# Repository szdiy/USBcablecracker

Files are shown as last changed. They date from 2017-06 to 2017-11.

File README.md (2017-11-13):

USBcablecracker
============
USB Cable Cracker is a device that measures the resistance of USB cable.
It measures the serial resistance of VCC + GND or D+ or D-.
And if you are not satisfy with the resistance, you can crack the cable by yourself.
It is a Arduino Leonardo compatible board, with some extend pins.

Schematic
------------
[PDF][schem]

BOM
------------
[CSV][bom]

PCB
------------
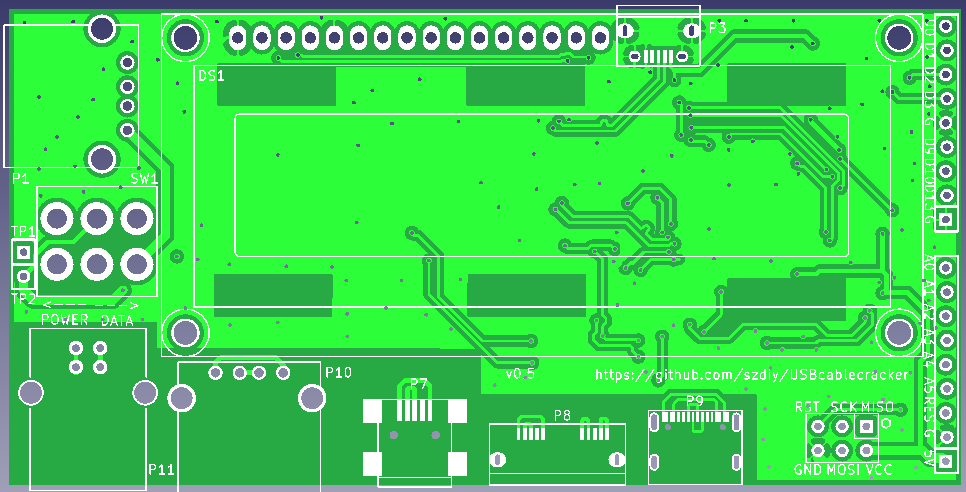
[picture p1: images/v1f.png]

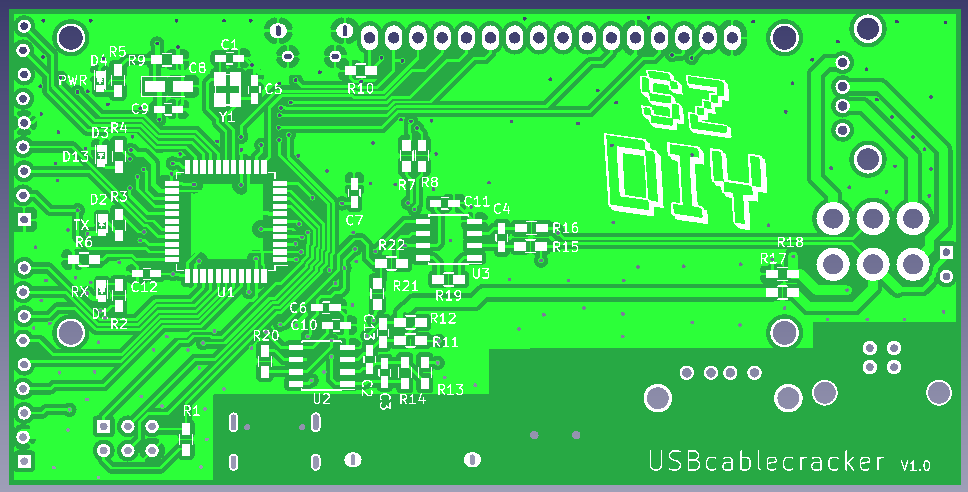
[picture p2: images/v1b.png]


Photo
------------

License
------------
This project is released under the CC BY-SA license.


Support
------------
r@szdiy.org

Where to buy
------------

[schem]:https://github.com/szdiy/USBcablecracker/raw/master/hardware/USBcablecracker.pdf
[bom]:https://github.com/szdiy/USBcablecracker/raw/master/hardware/manufature/USBcablecracker_bom.csv

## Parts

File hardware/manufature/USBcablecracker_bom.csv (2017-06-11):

Comment | Designator | Footprint
100nF/10V | C6,C9,C10,C11,C12 | C_0603
33R/1% | R18 | R_0603
68R/1% | R17 | R_0603
15PF | C1,C5 | C_0603
1nF | C2,C3,C4,C13 | C_0603
1uF | C7 | C_0603
LED_Yellow | D1 | LED_0603
TX_Green | D2 | LED_0603
LED_Blue | D3 | LED_0603
LED_Red | D4 | LED_0603
10K/1% | R1,R9,R11,R13,R15,R16,R20,R21,R22 | R_0603
1K/1% | R2,R3,R4,R5,R6 | R_0603
22R/1% | R7,R8 | R_0603
91R/1% | R10 | R_0603
100K/1% | R12,R14 | R_0603
11k/1% | R19 | R_0603
16MHz | Y1 | crystal_FA238-TSX3225
22uF/10V | C8 | Tantalum_Case-A_EIA-3216-18_Wave

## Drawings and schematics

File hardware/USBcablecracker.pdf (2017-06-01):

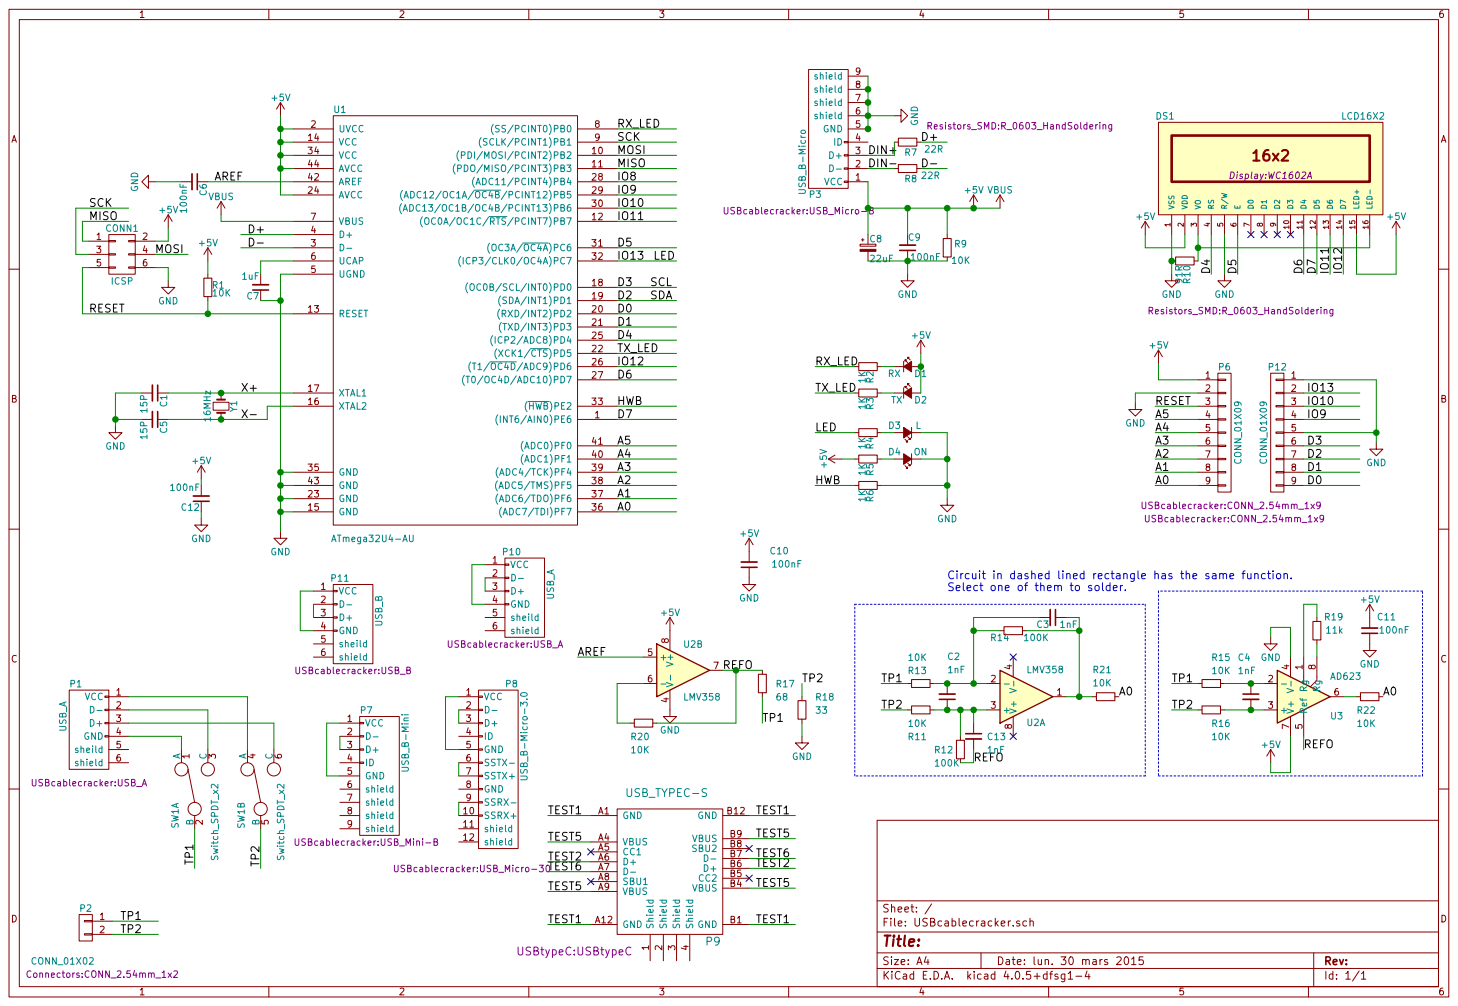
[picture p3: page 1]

1nF Circuit in dashed lined rectangle has the same function.
Select one of them to solder.

Id: 1/1 Title: File: USBcablecracker.sch Sheet: / R13

4 GND A1 GND B1 VBUS A4 VBUS B4 CC1 A5 CC2 B5 D+ A6 D+ B6 D- A7 D- B7 SBU1 A8 SBU2 B8 VBUS A9 VBUS B9 GND A12 GND B12 P9 USB_TYPEC-S

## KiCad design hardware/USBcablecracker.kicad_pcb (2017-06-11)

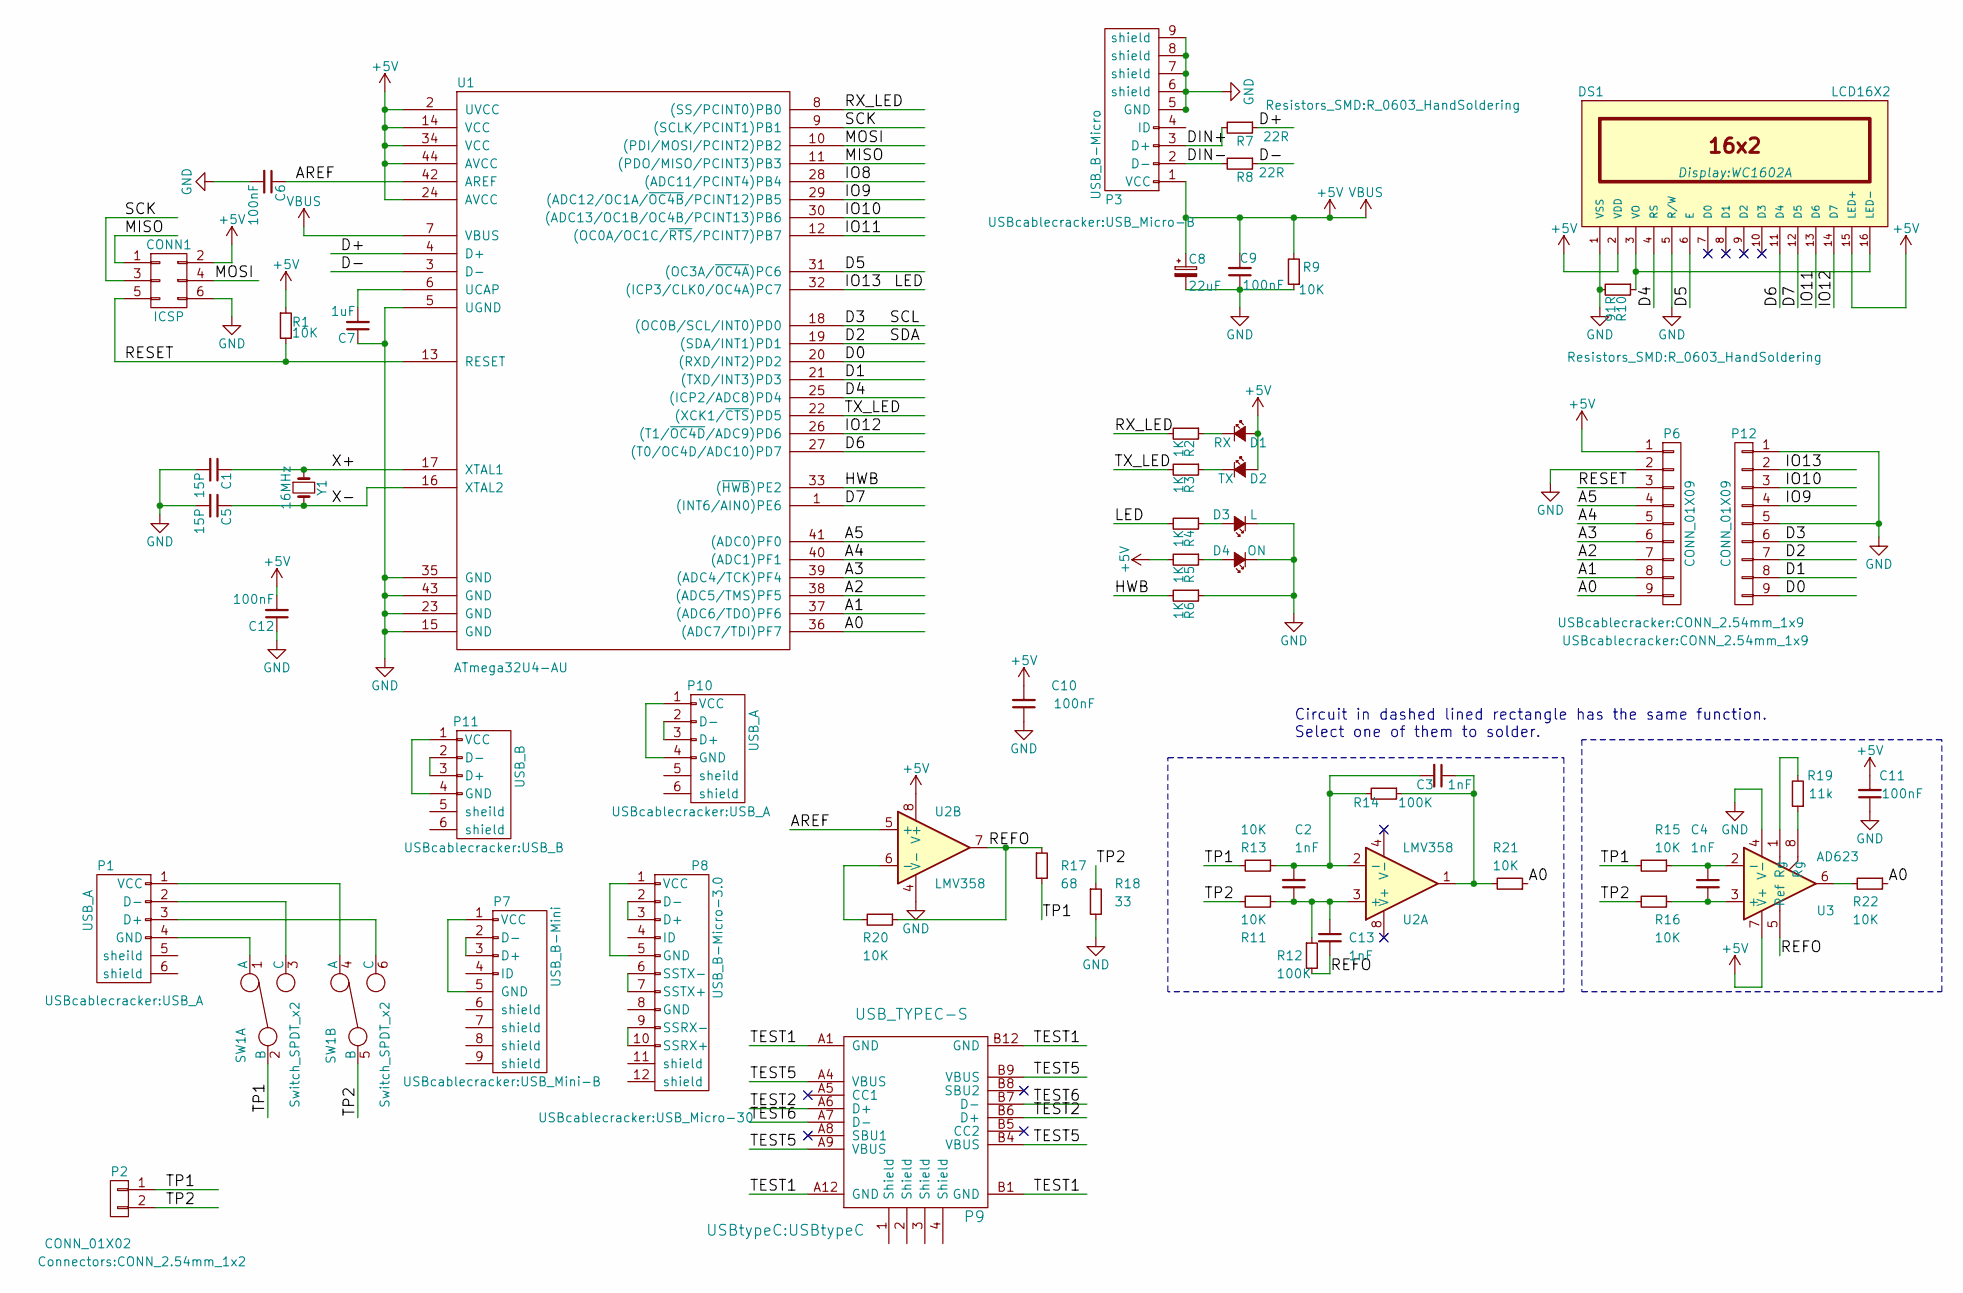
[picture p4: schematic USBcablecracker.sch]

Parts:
C1, C5: 15P; C_0603_HandSoldering
C2, C3, C4, C13: 1nF; C_0603_HandSoldering
C6, C9, C10, C11, C12: 100nF; C_0603_HandSoldering
C7: 1uF; C_0603_HandSoldering
C8: 22uF; Tantalum_Case-A_EIA-3216-18_Wave
CONN1: ICSP; CONN_2.54mm_2x3
D1: RX; LED_0603
D2: TX; LED_0603
D3: L; LED_0603
D4: ON; LED_0603
DS1: LCD16X2; WC1602A
P1, P10: USB_A
P2: CONN_01X02; CONN_2.54mm_1x2
P3: USB_B-Micro; USB_Micro-B
P6, P12: CONN_01X09; CONN_2.54mm_1x9
P7: USB_B-Mini; USB_Mini-B
P8: USB_B-Micro-3.0; USB_Micro-30
P9: USB_TYPEC-S; USBtypeC
P11: USB_B
R1, R9, R11, R13, R15, R16, R20, R21, R22: 10K; R_0603_HandSoldering
R2, R3, R4, R5, R6: 1K; R_0603_HandSoldering
R7, R8: 22R; R_0603_HandSoldering
R10: 91R; R_0603_HandSoldering
R12, R14: 100K; R_0603_HandSoldering
R17: 68; R_0603_HandSoldering
R18: 33; R_0603_HandSoldering
R19: 11k; R_0603_HandSoldering
SW1: Switch_SPDT_x2; DPDT
U1: ATmega32U4-AU; TQFP-44_10x10mm_Pitch0.8mm
U2: LMV358; SOIC-8_3.9x4.9mm_Pitch1.27mm
U3: AD623; SOIC-8_3.9x4.9mm_Pitch1.27mm
Y1: 16MHz; crystal_FA238-TSX3225

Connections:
+5C: C8.1, C9.2, C10.2, C11.2, C12.2, CONN1.2, D1.2 (A), D2.2 (A), DS1.2 (VDD), DS1.15 (LED+), P3.1 (VCC), P6.1, R1.1, R5.2, R9.2, U1.2 (UVCC), U1.7 (VBUS), U1.14 (VCC), U1.24 (AVCC), U1.34 (VCC), U1.44 (AVCC), U2.8 (V+), U3.7 (V+)
/A0: P6.9, R21.1, R22.1, U1.36 ((ADC7/TDI)PF7)
/A1: P6.8, U1.37 ((ADC6/TDO)PF6)
/A2: P6.7, U1.38 ((ADC5/TMS)PF5)
/A3: P6.6, U1.39 ((ADC4/TCK)PF4)
/A4: P6.5, U1.40 ((ADC1)PF1)
/A5: P6.4, U1.41 ((ADC0)PF0)
/AREF: C6.1, U1.42 (AREF), U2.5 (+)
/D0: P12.9, U1.20 ((RXD/INT2)PD2)
/D1: P12.8, U1.21 ((TXD/INT3)PD3)
/D2: P12.7, U1.19 ((SDA/INT1)PD1)
/D3: P12.6, U1.18 ((OC0B/SCL/INT0)PD0)
/D4: DS1.4 (RS), U1.25 ((ICP2/ADC8)PD4)
/D5: DS1.6 (E), U1.31 ((OC3A/~OC4A~)PC6)
/D6: DS1.11 (D4), U1.27 ((T0/OC4D/ADC10)PD7)
/D7: DS1.12 (D5), U1.1 ((INT6/AIN0)PE6)
/D+: R7.1, U1.4 (D+)
/D-: R8.1, U1.3 (D-)
/DIN+: P3.3 (D+), R7.2
/DIN-: P3.2 (D-), R8.2
/HWB: R6.2, U1.33 ((~HWB~)PE2)
/IO8: U1.28 ((ADC11/PCINT4)PB4)
/IO9: P12.4, U1.29 ((ADC12/OC1A/~OC4B~/PCINT12)PB5)
/IO10: P12.3, U1.30 ((ADC13/OC1B/OC4B/PCINT13)PB6)
/IO11: DS1.13 (D6), U1.12 ((OC0A/OC1C/~RTS~/PCINT7)PB7)
/IO12: DS1.14 (D7), U1.26 ((T1/~OC4D~/ADC9)PD6)
/IO13: P12.2, R4.2, U1.32 ((ICP3/CLK0/OC4A)PC7)
/MISO: CONN1.1, U1.11 ((PDO/MISO/PCINT3)PB3)
/MOSI: CONN1.4, U1.10 ((PDI/MOSI/PCINT2)PB2)
/REFO: C13.2, R12.2, R17.1, R20.1, U2.7, U3.5 (Ref)
/RESET: CONN1.5, P6.3, R1.2, U1.13 (RESET)
/RX_LED: R2.2, U1.8 ((SS/PCINT0)PB0)
/SCK: CONN1.3, U1.9 ((SCLK/PCINT1)PB1)
/TEST1: P9.A1 (GND), P9.A12 (GND), P9.B1 (GND), P9.B12 (GND)
/TEST2: P9.A6 (D+), P9.B6 (D+)
/TEST5: P9.A4 (VBUS), P9.A9 (VBUS), P9.B4 (VBUS), P9.B9 (VBUS)
/TEST6: P9.A7 (D-), P9.B7 (D-)
/TP1: P2.1, R13.2, R15.2, R17.2, SW1.2 (B)
/TP2: P2.2, R11.2, R16.2, R18.1, SW1.5 (B)
/TX_LED: R3.2, U1.22 ((XCK1/~CTS~)PD5)
/X+: C1.1, U1.17 (XTAL1), Y1.1
/X-: C5.1, U1.16 (XTAL2), Y1.2
GND: C1.2, C5.2, C6.2, C7.1, C8.2, C9.1, C10.1, C11.1, C12.1, CONN1.6, D3.1 (K), D4.1 (K), DS1.1 (VSS), DS1.5 (R/W), P3.5 (GND), P3.6 (shield), P3.7 (shield), P3.8 (shield), P3.9 (shield), P6.2, P12.1, P12.5, R6.1, R9.1, R10.2, R18.2, U1.5 (UGND), U1.15 (GND), U1.23 (GND), U1.35 (GND), U1.43 (GND), U2.4 (V-), U3.4 (V-)
unnamed: C2.2, C3.2, R13.1, R14.2, U2.2 (-)
unnamed: C3.1, R14.1, R21.2, U2.1
unnamed: C4.1, R15.1, U3.2 (-)
unnamed: C4.2, R16.1, U3.3 (+)
unnamed: C7.2, U1.6 (UCAP)
unnamed: C2.1, C13.1, R11.1, R12.1, U2.3 (+)
unnamed: D1.1 (K), R2.1
unnamed: D2.1 (K), R3.1
unnamed: D3.2 (A), R4.1
unnamed: D4.2 (A), R5.1
unnamed: DS1.3 (VO), DS1.16 (LED-), R10.1
unnamed: P1.1 (VCC), SW1.4 (A)
unnamed: P1.2 (D-), SW1.3 (C)
unnamed: P1.3 (D+), SW1.6 (C)
unnamed: P1.4 (GND), SW1.1 (A)
unnamed: P7.1 (VCC), P7.5 (GND)
unnamed: P7.2 (D-), P7.3 (D+)
unnamed: P8.1 (VCC), P8.5 (GND)
unnamed: P8.2 (D-), P8.3 (D+)
unnamed: P8.6 (SSTX-), P8.7 (SSTX+)
unnamed: P8.9 (SSRX-), P8.10 (SSRX+)
unnamed: P10.1 (VCC), P10.4 (GND)
unnamed: P10.2 (D-), P10.3 (D+)
unnamed: P11.1 (VCC), P11.4 (GND)
unnamed: P11.2 (D-), P11.3 (D+)
unnamed: R19.1, U3.8 (Rg)
unnamed: R19.2, U3.1 (Rg)
unnamed: R20.2, U2.6 (-)
unnamed: R22.2, U3.6

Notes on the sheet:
Circuit in dashed lined rectangle has the same function. Select one of them to solder.

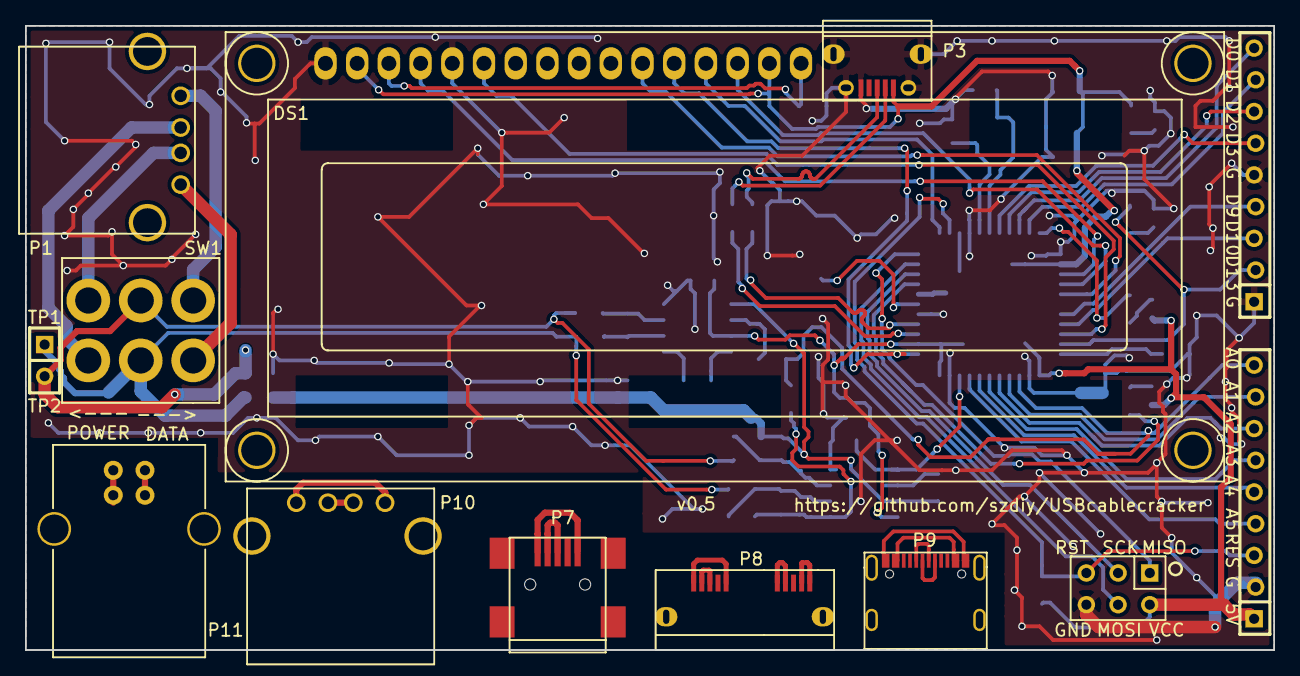
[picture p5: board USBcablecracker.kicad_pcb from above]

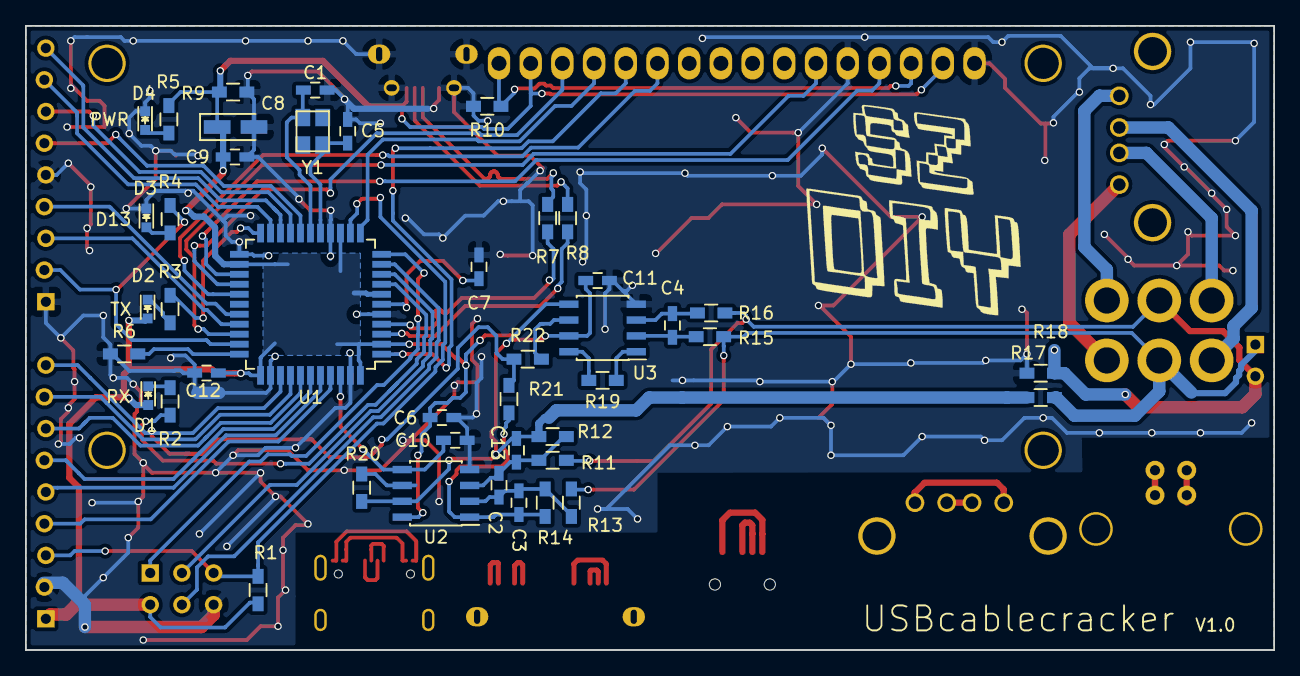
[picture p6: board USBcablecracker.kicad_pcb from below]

Board: 2 copper layers, 100.0 x 50.0 mm, 56 parts (43 on the bottom side), 71 nets.

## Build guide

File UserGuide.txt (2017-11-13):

USBCableCracker User Guide

The USBCableCracker is a instrument that measures the resistance of different types of USB cables.
And it is based on Arduino Leonardo.

Table of Contents:
1, how to use USBCableCracker
2, how does it work
3, hacking with it

How to use USBCableCracker
1) plug usb cable for power
    The power plug is P3 under the 1602 LCD, on the upper side of the PCB. Do not connect charger or computer with any other USB port, it will brake the board.
    And the cable to be test should be connect with P1 and any port on the bottom side.

2) select power or data cables to test.
   Turn the switch to left to measure two power wires(ie. VCC, GND), or turn the switch right to measure two data wire(D-, D+).

3) get result (and crack the cable if it is a bad cable)
    Since USBCableCracker test the serial resistance of both VCC GND wires, or D+ D- wires. The result is normally two times compare with single wire.
    In my opinion, to support two cables for proper charging with the current of 1A (to charge a 2000mA/h cellphone battery in 2 hours).
    In USB.org standard, it is at lease requires 4.4 V voltage for proper operation (7.3.2 Bus Timing/Electrical Characteristics and 7.2.2 Voltage Drop Budget). Assume that the charger output is 5.0V, with 1A charging current, the total resistance should lower than 0.6 Ohm.
    Some output of charger is up to 5.25V, thus, for proper operation to charge device with 1A current, the resistance of single wire should be no more than 0.425 Ohm.
    D- and D+ cable does not have to support high current, so it is vary possible that cable manufacturer make these two wires with thinner wire. In my opinion, it is good to use thinner wires, thinner wires is easy to bend.

2, How does it work
    The device measures the voltage drop with constant current.
    AREF is the internal 2.56V voltage reference provided by Atmega32u4. REFO in U2B is buffered output of AREF. Current through the cable is Vrefo/(R17 + R18 + Resistance of cable).
    Since cable resistance is small and can be ignored, the current is 2.56V / 101 Ohm = 25.34 mA, U2A and U3 has the same function of amplify the voltage drop by 10, the output voltage of U2A and U3 is Vrefo - 10 * (voltage drop of cable).
    And the output voltage (A0) is send to Pin 36 of Atmega32u4, which is an ADC pin. The MCU measure the voltage and convert it to digital value according to the function ADC_value = input_voltage * 1023 / reference_voltage. The voltage reference is selected to 2.56V internal voltage reference mentioned before.
    ADC_value = (2.56 / (2.56 - (10 * (33 + 68) * resistance)) ) * 1023 / 2.56
    Thus, the resistance between R17 and R18 is : resistance = 101 / 10 - (101 * ADC_value) / 10230

3, hack with it
    This board is based on Arduino Leonardo, you can do what ever you want with arduino IDE.
    I had made it a temperature sensor with DS18B20.

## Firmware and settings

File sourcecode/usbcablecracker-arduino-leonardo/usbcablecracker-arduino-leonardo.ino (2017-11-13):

/*
  LiquidCrystal Library - Hello World

 Demonstrates the use a 16x2 LCD display.  The LiquidCrystal
 library works with all LCD displays that are compatible with the
 Hitachi HD44780 driver. There are many of them out there, and you
 can usually tell them by the 16-pin interface.

 This sketch prints "Hello World!" to the LCD
 and shows the time.

  The circuit:
 * LCD RS pin to digital pin 12
 * LCD Enable pin to digital pin 11
 * LCD D4 pin to digital pin 5
 * LCD D5 pin to digital pin 4
 * LCD D6 pin to digital pin 3
 * LCD D7 pin to digital pin 2
 * LCD R/W pin to ground
 * LCD VSS pin to ground
 * LCD VCC pin to 5V
 * 10K resistor:
 * ends to +5V and ground
 * wiper to LCD VO pin (pin 3)

 Library originally added 18 Apr 2008
 by David A. Mellis
 library modified 5 Jul 2009
 by Limor Fried (http://www.ladyada.net)
 example added 9 Jul 2009
 by Tom Igoe
 modified 22 Nov 2010
 by Tom Igoe

 This example code is in the public domain.

 http://www.arduino.cc/en/Tutorial/LiquidCrystal
 */

// include the library code:
#include <LiquidCrystal.h>

// initialize the library with the numbers of the interface pins
// LiquidCrystal lcd(12, 11, 5, 4, 3, 2);
// LiquidCrystal lcd(12, 11, 7, 6, 5, 4);
LiquidCrystal lcd (4, 5, 6, 7, 11, 12);

int analogPin0 = 0;
int analogPin1 = 1;

/********************************************************************/
// First we include the libraries
#include <OneWire.h>
#include <DallasTemperature.h>
/********************************************************************/
// Data wire is plugged into pin 2 on the Arduino
// #define ONE_WIRE_BUS 13
/********************************************************************/
// Setup a oneWire instance to communicate with any OneWire devices
// (not just Maxim/Dallas temperature ICs)
// OneWire oneWire(ONE_WIRE_BUS);
/********************************************************************/
// Pass our oneWire reference to Dallas Temperature.
// DallasTemperature sensors(&oneWire);
/********************************************************************/



void setup()
{
  // set up the LCD's number of columns and rows:
  lcd.begin (16, 2);
  // Print a message to the LCD.
  lcd.print ("hello, world!");

  // Rafael Analog Ref
  analogReference (INTERNAL);
  // analogReference(INTERNAL2V56);
  //type: which type of reference to use (DEFAULT, INTERNAL, INTERNAL1V1, INTERNAL2V56, or EXTERNAL).
  // https://www.arduino.cc/en/Reference/analogReference
  // analogReference (INTERNAL1V1);           // compile sound
  // analogReference (2);     // for INTERNAL1V1 but not defined by arduiho.h for Atmega328P

  ADMUX |= (1 << REFS0) | (1 << REFS1);  // datasheet page 250 and 262, output internal reference voltage.

  // ADMUX |= 1<<REFS0;      // datasheet page 250 and 262, output internal reference voltage.
  // ADMUX &= 0xFF ^ (1<<REFS1);


  ////////////////////////////////////////////////////////////////////////////
  // start serial port
  Serial.begin(9600);
  Serial.println("Dallas Temperature IC Control Library Demo");
  // Start up the library
  // sensors.begin();
  ////////////////////////////////////////////////////////////////////////////

}

void loop()
{
  int val;
  float resistance;
  delay (200);
  // set the cursor to column 0, line 1
  // (note: line 1 is the second row, since counting begins with 0):
  lcd.setCursor (0, 0);
  lcd.print ("                ");
  // print the number of seconds since reset:
  // lcd.print(millis() / 1000);


  lcd.setCursor (0, 1);
  lcd.print ("    ");
  val = analogRead (analogPin0);
  delay(1);
  val = analogRead (analogPin0);
  delay(1);
  lcd.setCursor (0, 1);
  lcd.print (val);


  lcd.setCursor (4, 1);
  lcd.print ("    ");
  // val = analogRead(analogPin0);
  // resistance = val;
  // current source voltage: Vref
  // current source resistor 1 and 2: 68 Ohm and 33 Ohm
  // Instrumation Amplifier Gain: 10

  // resistance = 101 / 10 - (101 * value) / 10230
  resistance = 10.1 - 0.00987292277614858 * val;

  lcd.setCursor (4, 1);
  lcd.print (resistance);
  lcd.print ("ohm ");

  // lcd.print ("    ");
  // val = analogRead (analogPin1);
  // lcd.setCursor (4, 1);
  // lcd.print (val);



  lcd.setCursor (0, 0);
  lcd.print ("                ");
  lcd.setCursor (0, 0);
  if (resistance < 0.6)
  {
    lcd.print ("Flawless cable!");
  }
  else if (resistance < 1)
  {
    lcd.print ("Good cable!");
  }
  else if (resistance < 2)
  {
    lcd.print ("Barely useful.");
  }
  else if (resistance < 3)
  {
    lcd.print ("Cut it!");
  }
  else if (resistance < 4)
  {
    lcd.print ("Throw it away!");
  }
  else if (resistance < 6)
  {
    lcd.print ("At your own risk!");
  }
  else if (resistance > 10)
  {
    lcd.print ("                ");
  }
  // lcd.scrollDisplayLeft();
  // lcd.autoscroll();


  ////////////////////////////////////////////////////////////////////////////
  // call sensors.requestTemperatures() to issue a global temperature
  // request to all devices on the bus
  /********************************************************************/
  // Serial.print(" Requesting temperatures...");
  // sensors.requestTemperatures(); // Send the command to get temperature readings
  // Serial.println("DONE");
  /********************************************************************/
  // Serial.print("Temperature is: ");
  // lcd.setCursor (11, 1);
  // lcd.print("         ");
  // lcd.setCursor (11, 1);
  // lcd.print(sensors.getTempCByIndex(0)); // Why "byIndex"?
  // You can have more than one DS18B20 on the same bus.
  // 0 refers to the first IC on the wire
  // delay(750); // 18B20 need 750ms sampling time

}

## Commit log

2016-12-23 alpha version
    [USBcablecracker-B.Cu.gbr, USBcablecracker-B.Mask.gbr, USBcablecracker-B.SilkS.gbr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]
2017-02-25 update pcb
    [USBcablecracker.dsn, USBcablecracker.kicad_pcb, USBcablecracker.sch]
2017-05-08 Version 0.4 finished. Solved UCAP inner linear regulator problem. Modified library, footprints, instrumentation amplifier common mode input voltage, modified AREF output load.
    [USBcablecracker-B.Cu.gbr, USBcablecracker-B.Mask.gbr, USBcablecracker-B.SilkS.gbr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]
2017-05-10 Modified two 9-pin header distance and modified all via with not net to net GND. Add gitinore file.
    [USBcablecracker.kicad_pcb]
2017-05-10 updated gerber
    [USBcablecracker-B.Cu.gbr, USBcablecracker-B.Mask.gbr, USBcablecracker-B.SilkS.gbr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]
2017-10-05 Move arduino project file to a folder with the same name
2017-10-05 Remove DS18B20 temperature sensor
